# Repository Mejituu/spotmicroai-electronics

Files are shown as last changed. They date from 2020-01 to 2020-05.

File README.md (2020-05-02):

# Custom version of BostonDynamics Spot robot



BostonDynamics Spot robot: https://www.youtube.com/watch?v=wlkCQXHEgjA

Can you make it dance? join the challenge: https://www.youtube.com/watch?v=kHBcVlqpvZ8&list=PLp5v7U2tXHs3BYfe93GZwuUZLGsisapic&index=2

Original idea by KDY0523 https://www.thingiverse.com/thing:3445283

Some of the community videos: https://www.youtube.com/playlist?list=PLp5v7U2tXHs3BYfe93GZwuUZLGsisapic

* Join us in Slack: https://spotmicroai-inviter.herokuapp.com/
* Documentation: https://spotmicroai.readthedocs.io
* Forum http://spotmicroai.org/

This is the repository for Electronic schemas of SpotMicro project.

In here you can find all the project repositories: **https://gitlab.com/custom_robots/spotmicro**

# Electronics repository of SpotMicro project

The folder arrangement follows the convention:

* Gitlab username
* Name that the user pics for the schematics

For example franferri/SpotMicro with Raspberry Pi v1

# Example file



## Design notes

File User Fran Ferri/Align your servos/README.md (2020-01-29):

Remember to align your servos before mounting.
Also to test them before you mount, in case some are presenting excessive jitter.

To thest them use the script align_mounted_servos.py in this folder.

Make sure you have the I2C interface connected in raspberry, in the Interfacing Options
```
sudo raspi-config
```

```
ssh pi@192.168.1.XX

cd "projects/electronics/Align your servos/script"

sudo apt-get install python3-venv -y
python3 -m venv venv --clear
source venv/bin/activate

curl https://bootstrap.pypa.io/get-pip.py | python

pip install --upgrade pip
pip install --upgrade setuptools
python3 -m pip install smbus
python3 -m pip install RPi.GPIO

python3 align_mounted_servos.py
```

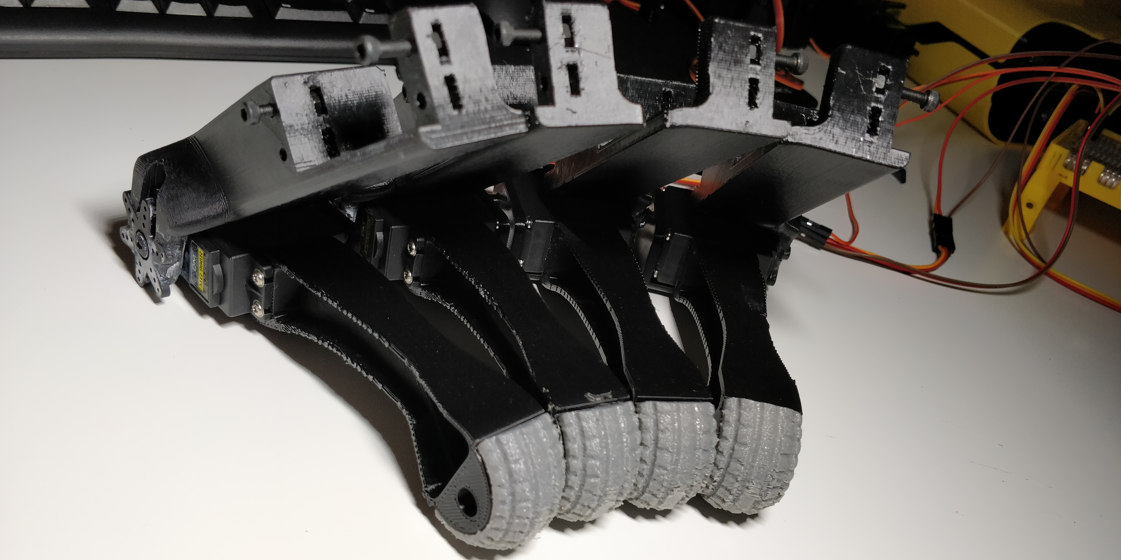
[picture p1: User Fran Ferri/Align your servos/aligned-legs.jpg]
aligned-legs


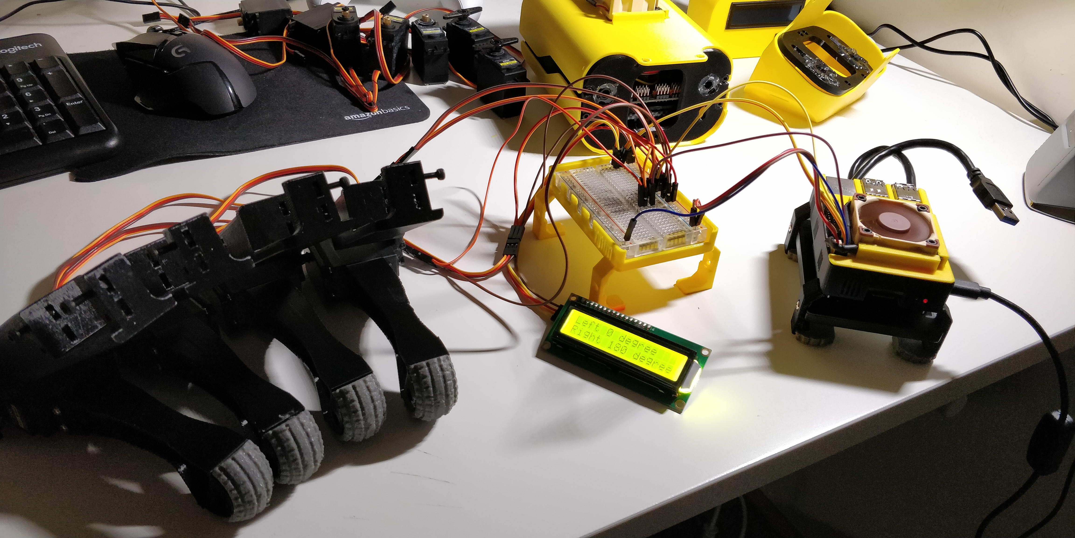
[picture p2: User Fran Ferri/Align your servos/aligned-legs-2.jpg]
aligned-legs-2


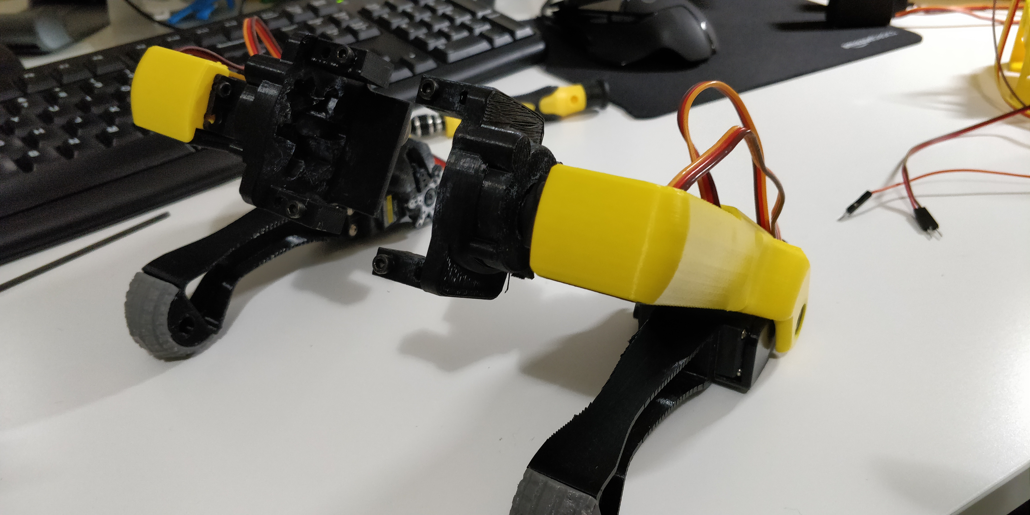
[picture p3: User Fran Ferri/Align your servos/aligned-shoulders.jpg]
aligned-shoulders


For me the trick was:
* lower part of the leg: max 90º and 180º and adjust them as in the picture (different angles since right or left are the opposite)
* Mind servos, 90º, then center the horns and mount
* Shoulder servos 90º, then center the horns and mount

Some videos to give you an idea of what I did:

**SpotMicro - Jittering servo, need a replacement**

SpotMicro - Jittering servo, need a replacement (http://www.youtube.com/watch?v=7d3iO5jCroM "")

**SpotMicro - Aligning servos 1**

SpotMicro - Aligning servos 1 (http://www.youtube.com/watch?v=tBt8xCcZeH0 "")

**SpotMicro - Aligning servos 2**

SpotMicro - Aligning servos 2 (http://www.youtube.com/watch?v=m_V5X4ZloSo "")

**SpotMicro - Aligning servos 3**

SpotMicro - Aligning servos 3 (http://www.youtube.com/watch?v=I0enRPsiIeQ "")

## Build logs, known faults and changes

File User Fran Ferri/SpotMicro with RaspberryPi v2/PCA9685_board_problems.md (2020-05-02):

The generic PCA9685 board that you can buy everywhere has the following problems.

Problems:

* When you shut it down resets the controller in the board and the legs may jump to unpredictable positions, same efects when you re-enable the power in the board.

* The board takes 6v max for the servo power cirquit.

Solutions:

* You can feed any voltage you like if you power the servos directly in the very same servos connections in the board, the cirquit is isolated from the board one. Don't do this is you already have a board with a burned diode.
Mind than you are bypasing the capacitor this way. Is not ideal. But you can feed with any amount of voltage and amp that the board lanes can't take without affecting the board functions.

* If you go this path use a relay since you are bypasing the 0E conector

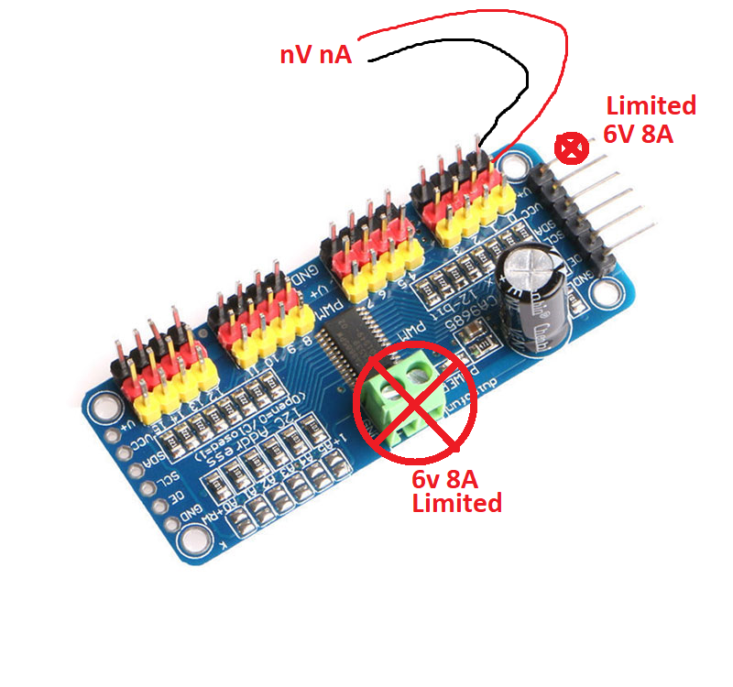
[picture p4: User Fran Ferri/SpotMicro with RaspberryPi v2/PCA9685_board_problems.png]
PCA9685_bypass_connection


Sources of this ideas: https://forums.adafruit.com/viewtopic.php?f=8&t=163440&p=803328#p803328

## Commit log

2020-01-08 Basich schema added
    [SpotMicro guts.fzz]
2020-01-18 Updated franferri SpotMicro schema 1
    [SpotMicro guts.fzz, SpotMicro with Raspberry Pi.fzz]
2020-01-18 Applying folder convention
    [SpotMicro with Raspberry Pi.fzz]
2020-01-18 Added missing power line
    [SpotMicro with Raspberry Pi.fzz]
2020-01-25 added some instructions to align servos
2020-05-01 Organizing the simulation repo to allow many users
    [SpotMicro with Raspberry Pi.fzz]
